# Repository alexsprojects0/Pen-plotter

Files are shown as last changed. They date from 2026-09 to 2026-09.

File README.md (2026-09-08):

# Pen-plotter
A 180mm × 106.5mm pen plotter, driven by four 28BYJ-48 stepper motors. It can run on any microcontroller with at least 12 output pins, but all my code is written for the Arduino Uno.

Items list
2 (608-2RS bearings)
1 (Pen)
4 (28BYJ-48 stepper motors)
~200g (filament)
2 (M3 bolts any size)
2 (M3 bolts 7mm or less)
2 (M3 bolts 10mm or less)
1 (Power supply ~5 volts and at least 2amps)

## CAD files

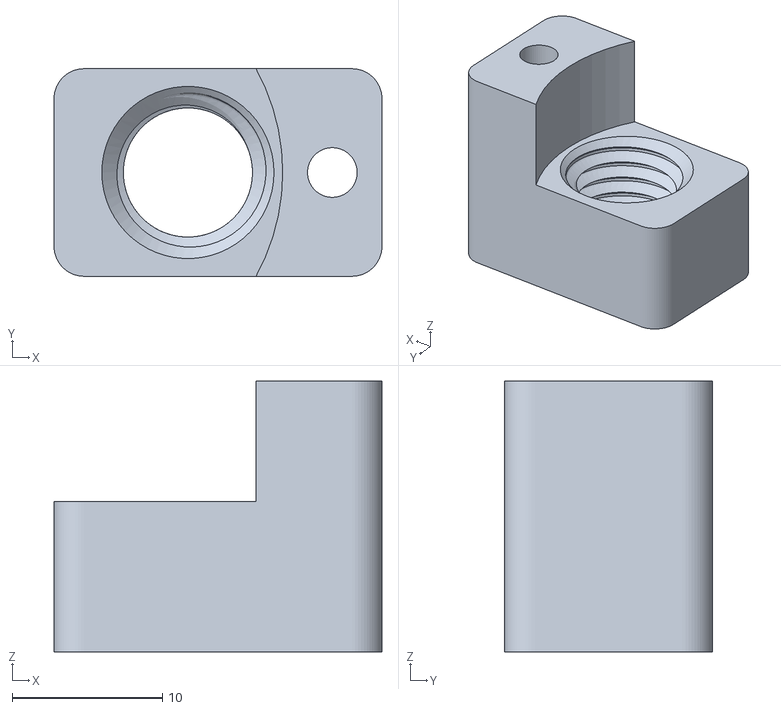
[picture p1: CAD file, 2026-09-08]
pen holder.stl
21.8 x 13.8 x 18.0

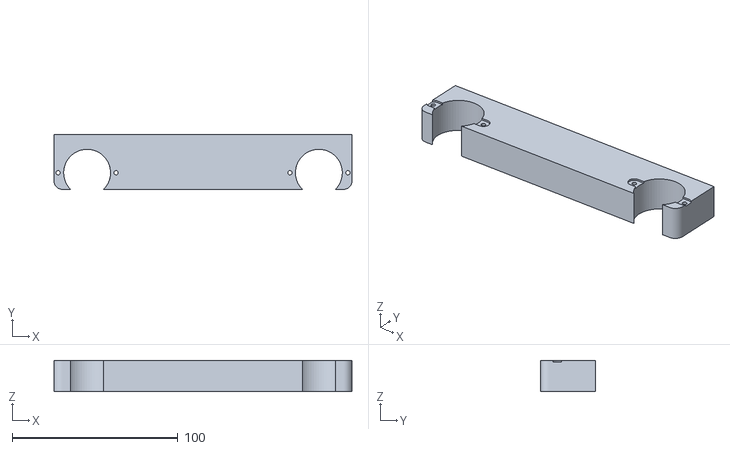
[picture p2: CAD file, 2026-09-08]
y axis base.stl
180.0 x 33.0 x 19.0

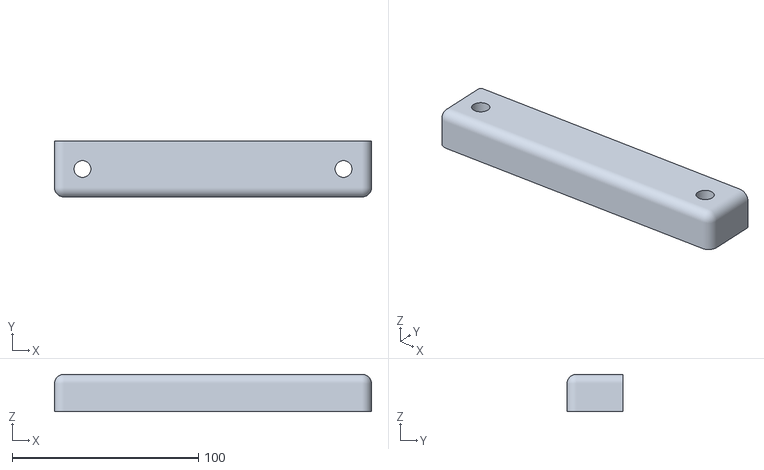
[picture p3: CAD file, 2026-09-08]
y axis support.stl
170.0 x 30.0 x 20.0

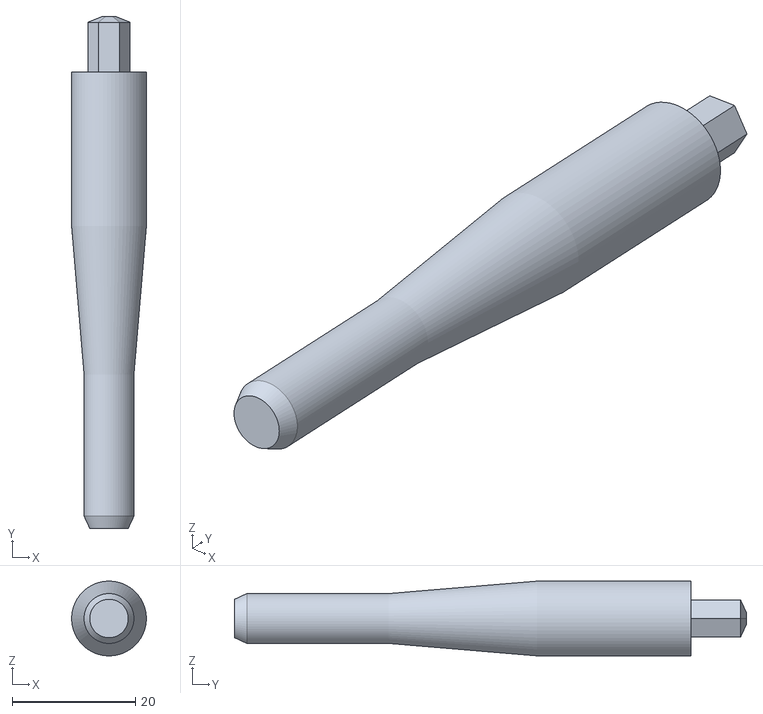
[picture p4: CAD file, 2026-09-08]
coulper.stl
12.1 x 83.0 x 12.1

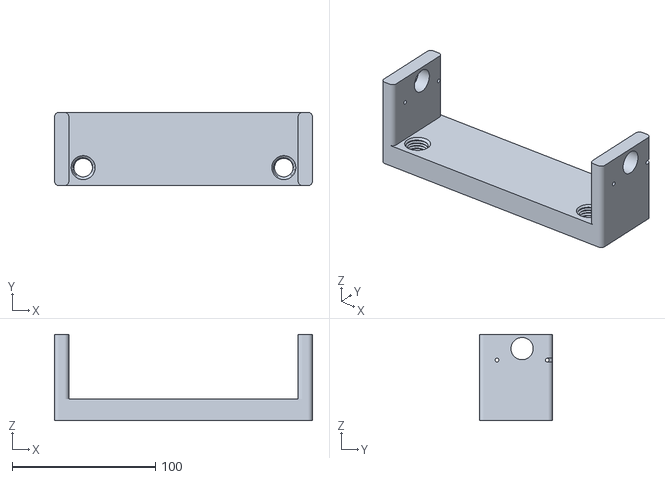
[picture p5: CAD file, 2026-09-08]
x axis base.stl
180.0 x 51.0 x 60.3

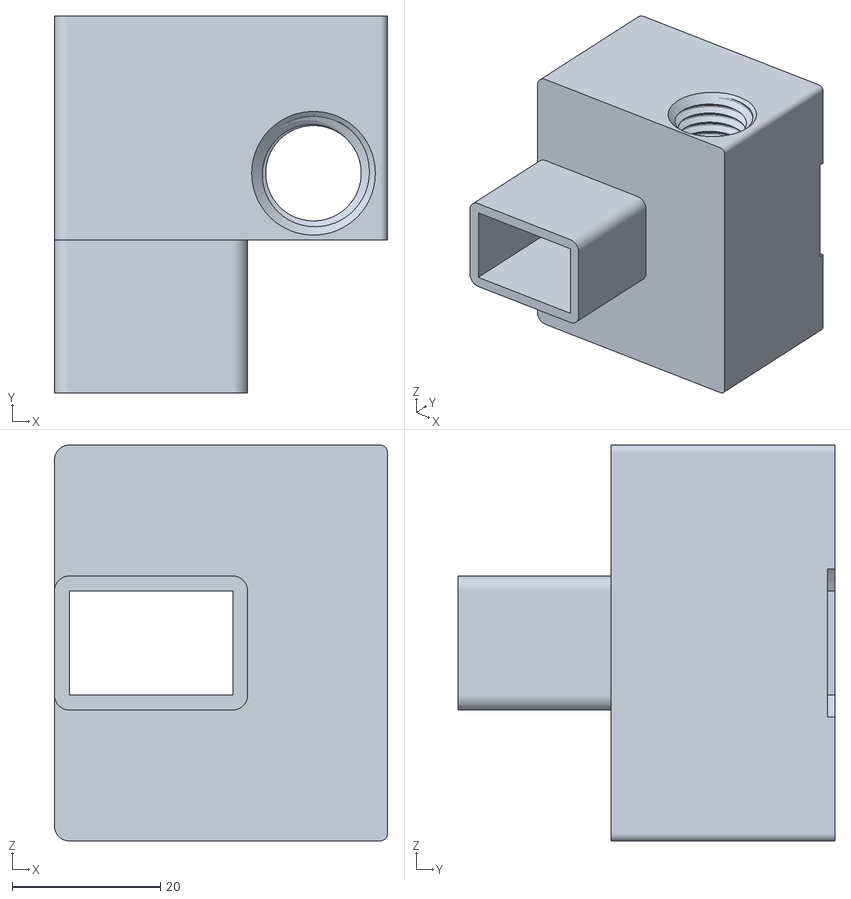
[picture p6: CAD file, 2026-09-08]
z axis base.stl
45.0 x 50.9 x 53.5

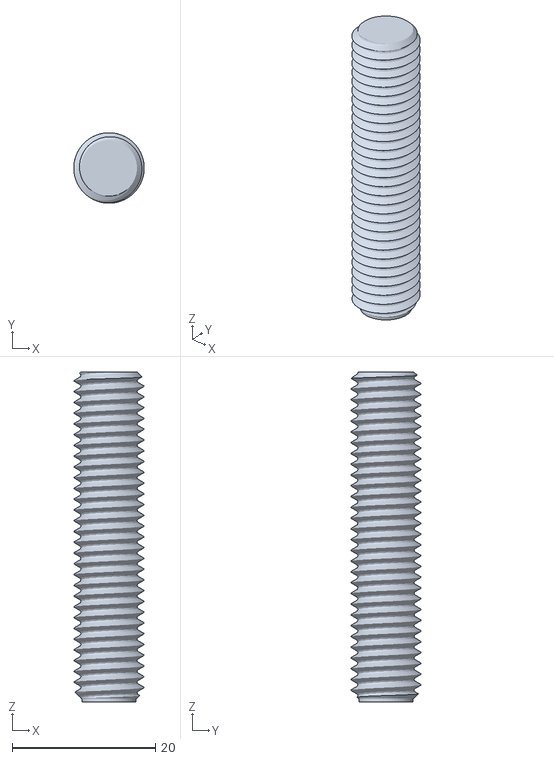
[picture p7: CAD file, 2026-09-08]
z screw.stl
9.83 x 9.83 x 46.0

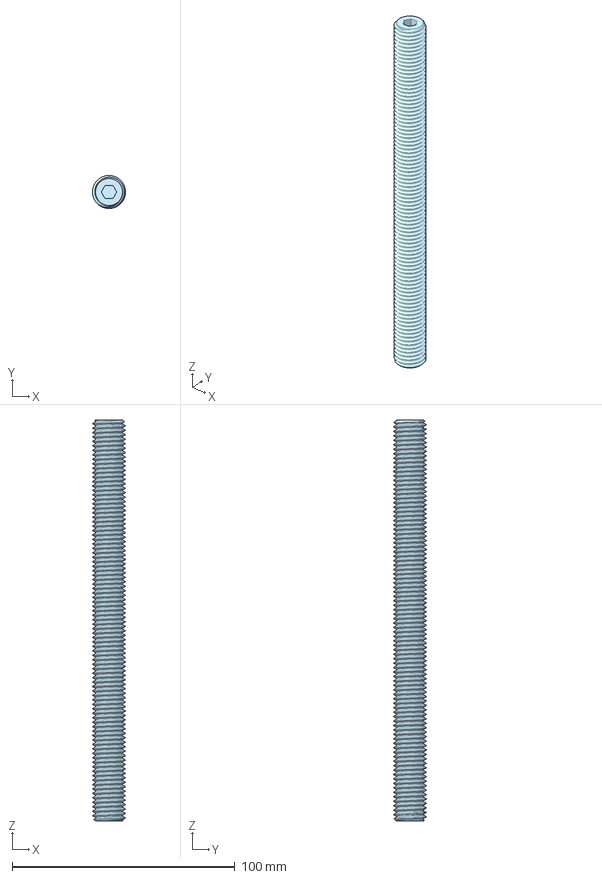
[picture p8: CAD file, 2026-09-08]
180mm screw.step
14.8 x 14.8 x 180.0 mm

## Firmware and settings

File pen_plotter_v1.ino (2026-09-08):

/*
  Pen plotter firmware - Arduino Uno, 4x 28BYJ-48 + ULN2003

  Axes: X (1 motor, 2mm pitch, 0-105mm), Y (2 motors, 2mm pitch, 0-166mm),
  Z (1 motor, 1.5mm pitch).

    Motor   IN1  IN2  IN3  IN4
    X       2    4    3    5
    Y1      6    8    7    9
    Y2      10   12   11   13
    Z       A0   A2   A1   A3

  Serial protocol (9600 baud):
    G1 X<mm> Y<mm>      move to position
    M3 / M5             pen down / pen up
    M2                  end job, return to 0,0
    JOGZ<mm>             nudge Z (+ down, - up)
    JOGX<mm> / JOGY<mm> nudge X/Y directly
    SETPOS X<mm> Y<mm>  set current position without moving
    SETDOWN / SETUP     mark current Z as down/up without moving
*/

#include <AccelStepper.h>
#include <MultiStepper.h>

#define X_IN1 2
#define X_IN2 4
#define X_IN3 3
#define X_IN4 5

#define Y1_IN1 6
#define Y1_IN2 8
#define Y1_IN3 7
#define Y1_IN4 9

#define Y2_IN1 10
#define Y2_IN2 12
#define Y2_IN3 11
#define Y2_IN4 13

#define Z_IN1 A0
#define Z_IN2 A2
#define Z_IN3 A1
#define Z_IN4 A3

const float STEPS_PER_REV = 4096.0;

const float X_PITCH_MM = 2.0;
const float Y_PITCH_MM = 2.0;
const float Z_PITCH_MM = 1.5;

const float X_STEPS_PER_MM = STEPS_PER_REV / X_PITCH_MM;
const float Y_STEPS_PER_MM = STEPS_PER_REV / Y_PITCH_MM;
const float Z_STEPS_PER_MM = STEPS_PER_REV / Z_PITCH_MM;

const float X_MAX_MM = 105.0;
const float Y_MAX_MM = 166.0;

const float Z_LIFT_MM = 3.0;
const long  Z_LIFT_STEPS = (long)(Z_LIFT_MM * Z_STEPS_PER_MM);

const float XY_MAX_SPEED = 350.0;
const float Z_MAX_SPEED  = 300.0;

AccelStepper motorX (AccelStepper::HALF4WIRE, X_IN1, X_IN3, X_IN2, X_IN4);
AccelStepper motorY1(AccelStepper::HALF4WIRE, Y1_IN1, Y1_IN3, Y1_IN2, Y1_IN4);
AccelStepper motorY2(AccelStepper::HALF4WIRE, Y2_IN1, Y2_IN3, Y2_IN2, Y2_IN4);
AccelStepper motorZ (AccelStepper::HALF4WIRE, Z_IN1, Z_IN3, Z_IN2, Z_IN4);

MultiStepper xySync;

float curX_mm = 0.0;
float curY_mm = 0.0;
bool penIsDown = true;

void setup() {
  Serial.begin(9600);

  motorX.setMaxSpeed(XY_MAX_SPEED);
  motorY1.setMaxSpeed(XY_MAX_SPEED);
  motorY2.setMaxSpeed(XY_MAX_SPEED);
  motorZ.setMaxSpeed(Z_MAX_SPEED);

  xySync.addStepper(motorX);
  xySync.addStepper(motorY1);
  xySync.addStepper(motorY2);

  Serial.println(F("Pen plotter ready. Assumes pen DOWN at X0 Y0."));
  Serial.println(F("ok"));
}

void loop() {
  if (Serial.available()) {
    String line = Serial.readStringUntil('\n');
    line.trim();
    if (line.length() > 0) {
      handleCommand(line);
      Serial.println(F("ok"));
    }
  }
}

void handleCommand(String cmd) {
  cmd.toUpperCase();

  if (cmd.startsWith("G1")) {
    float targetX = curX_mm;
    float targetY = curY_mm;

    int xIdx = cmd.indexOf('X');
    int yIdx = cmd.indexOf('Y');

    if (xIdx != -1) targetX = cmd.substring(xIdx + 1).toFloat();
    if (yIdx != -1) targetY = cmd.substring(yIdx + 1).toFloat();

    moveTo(targetX, targetY);
  }
  else if (cmd.startsWith("M3")) {
    penDown();
  }
  else if (cmd.startsWith("M5")) {
    penUp();
  }
  else if (cmd.startsWith("M2")) {
    endJob();
  }
  else if (cmd.startsWith("JOGX")) {
    float jogMm = cmd.substring(4).toFloat();
    long jogSteps = (long)(jogMm * X_STEPS_PER_MM);
    motorX.move(jogSteps);
    runToCompletion(motorX);
    disableXY();
  }
  else if (cmd.startsWith("JOGY")) {
    float jogMm = cmd.substring(4).toFloat();
    long jogSteps = (long)(jogMm * Y_STEPS_PER_MM);
    motorY1.move(jogSteps);
    motorY2.move(jogSteps);
    runToCompletionTwo(motorY1, motorY2);
    disableXY();
  }
  else if (cmd.startsWith("JOGZ")) {
    float jogMm = cmd.substring(3).toFloat();
    long jogSteps = (long)(jogMm * Z_STEPS_PER_MM);
    motorZ.move(jogSteps);
    runToCompletion(motorZ);
    disableZ();
  }
  else if (cmd.startsWith("SETPOS")) {
    int xIdx = cmd.indexOf('X');
    int yIdx = cmd.indexOf('Y');
    if (xIdx != -1) curX_mm = cmd.substring(xIdx + 1).toFloat();
    if (yIdx != -1) curY_mm = cmd.substring(yIdx + 1).toFloat();
    Serial.print(F("Position set to X"));
    Serial.print(curX_mm);
    Serial.print(F(" Y"));
    Serial.println(curY_mm);
  }
  else if (cmd.startsWith("SETDOWN")) {
    penIsDown = true;
    Serial.println(F("Marked current position as pen-down."));
  }
  else if (cmd.startsWith("SETUP")) {
    penIsDown = false;
    Serial.println(F("Marked current position as pen-up."));
  }
  else {
    Serial.print(F("Unknown command: "));
    Serial.println(cmd);
  }
}

void moveTo(float xmm, float ymm) {
  xmm = constrain(xmm, 0.0, X_MAX_MM);
  ymm = constrain(ymm, 0.0, Y_MAX_MM);

  long xSteps = (long)(xmm * X_STEPS_PER_MM);
  long ySteps = (long)(ymm * Y_STEPS_PER_MM);

  long targets[3] = { xSteps, ySteps, ySteps };
  xySync.moveTo(targets);

  while (xySync.run()) {}

  curX_mm = xmm;
  curY_mm = ymm;

  disableXY();
}

void penDown() {
  if (!penIsDown) {
    motorZ.move(Z_LIFT_STEPS);
    runToCompletion(motorZ);
    penIsDown = true;
    disableZ();
  }
}

void penUp() {
  if (penIsDown) {
    motorZ.move(-Z_LIFT_STEPS);
    runToCompletion(motorZ);
    penIsDown = false;
    disableZ();
  }
}

void endJob() {
  penUp();
  moveTo(0.0, 0.0);
  disableXY();
  disableZ();
  Serial.println(F("Job complete. Returned to origin, pen up."));
}

void runToCompletion(AccelStepper &motor) {
  motor.setSpeed(motor.maxSpeed());
  while (motor.distanceToGo() != 0) {
    motor.runSpeedToPosition();
  }
}

void runToCompletionTwo(AccelStepper &m1, AccelStepper &m2) {
  m1.setSpeed(m1.maxSpeed());
  m2.setSpeed(m2.maxSpeed());
  while (m1.distanceToGo() != 0 || m2.distanceToGo() != 0) {
    if (m1.distanceToGo() != 0) m1.runSpeedToPosition();
    if (m2.distanceToGo() != 0) m2.runSpeedToPosition();
  }
}

void disableXY() {
  motorX.disableOutputs();
  motorY1.disableOutputs();
  motorY2.disableOutputs();
}

void disableZ() {
  motorZ.disableOutputs();
}

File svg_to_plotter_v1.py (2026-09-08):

#!/usr/bin/env python3
"""
Converts SVG line art into the plotter's serial protocol (G1/M3/M5/M2)
and streams it to the Arduino over USB.

Usage:
    python svg_to_plotter.py drawing.svg --port COM5
    python svg_to_plotter.py drawing.svg --dry-run
"""

import argparse
import math
import re
import sys
import time
import xml.etree.ElementTree as ET

BED_X_MM = 105.0
BED_Y_MM = 166.0
MARGIN_MM = 5.0

CURVE_SEGMENTS = 20

TOKEN_RE = re.compile(r"[MmLlHhVvCcSsQqTtAaZz]|-?\d*\.?\d+(?:[eE][-+]?\d+)?")


def parse_path_d(d):
    tokens = TOKEN_RE.findall(d)
    i = 0

    def next_num():
        nonlocal i
        val = float(tokens[i])
        i += 1
        return val

    subpaths = []
    current = []
    cur = (0.0, 0.0)
    start = (0.0, 0.0)
    last_ctrl = None
    cmd = None

    while i < len(tokens):
        tok = tokens[i]
        if re.match(r"[A-Za-z]", tok):
            cmd = tok
            i += 1

        if cmd in ("M", "m"):
            x, y = next_num(), next_num()
            if cmd == "m" and current:
                x += cur[0]; y += cur[1]
            if current:
                subpaths.append(current)
            current = [(x, y)]
            cur = (x, y)
            start = cur
            last_ctrl = None
            cmd = "L" if cmd == "M" else "l"

        elif cmd in ("L", "l"):
            x, y = next_num(), next_num()
            if cmd == "l":
                x += cur[0]; y += cur[1]
            current.append((x, y))
            cur = (x, y)
            last_ctrl = None

        elif cmd in ("H", "h"):
            x = next_num()
            if cmd == "h":
                x += cur[0]
            current.append((x, cur[1]))
            cur = (x, cur[1])
            last_ctrl = None

        elif cmd in ("V", "v"):
            y = next_num()
            if cmd == "v":
                y += cur[1]
            current.append((cur[0], y))
            cur = (cur[0], y)
            last_ctrl = None

        elif cmd in ("C", "c"):
            x1, y1, x2, y2, x, y = (next_num() for _ in range(6))
            if cmd == "c":
                x1 += cur[0]; y1 += cur[1]
                x2 += cur[0]; y2 += cur[1]
                x += cur[0]; y += cur[1]
            current.extend(_cubic_bezier(cur, (x1, y1), (x2, y2), (x, y)))
            cur = (x, y)
            last_ctrl = (x2, y2)

        elif cmd in ("S", "s"):
            x2, y2, x, y = (next_num() for _ in range(4))
            if cmd == "s":
                x2 += cur[0]; y2 += cur[1]
                x += cur[0]; y += cur[1]
            if last_ctrl:
                x1 = 2 * cur[0] - last_ctrl[0]
                y1 = 2 * cur[1] - last_ctrl[1]
            else:
                x1, y1 = cur
            current.extend(_cubic_bezier(cur, (x1, y1), (x2, y2), (x, y)))
            cur = (x, y)
            last_ctrl = (x2, y2)

        elif cmd in ("Q", "q"):
            x1, y1, x, y = (next_num() for _ in range(4))
            if cmd == "q":
                x1 += cur[0]; y1 += cur[1]
                x += cur[0]; y += cur[1]
            current.extend(_quad_bezier(cur, (x1, y1), (x, y)))
            cur = (x, y)
            last_ctrl = (x1, y1)

        elif cmd in ("T", "t"):
            x, y = next_num(), next_num()
            if cmd == "t":
                x += cur[0]; y += cur[1]
            if last_ctrl:
                x1 = 2 * cur[0] - last_ctrl[0]
                y1 = 2 * cur[1] - last_ctrl[1]
            else:
                x1, y1 = cur
            current.extend(_quad_bezier(cur, (x1, y1), (x, y)))
            cur = (x, y)
            last_ctrl = (x1, y1)

        elif cmd in ("A", "a"):
            rx, ry, rot, large, sweep, x, y = (next_num() for _ in range(7))
            if cmd == "a":
                x += cur[0]; y += cur[1]
            current.append((x, y))
            cur = (x, y)
            last_ctrl = None

        elif cmd in ("Z", "z"):
            current.append(start)
            cur = start
            subpaths.append(current)
            current = []
            last_ctrl = None

        else:
            i += 1

    if current:
        subpaths.append(current)
    return subpaths


def _cubic_bezier(p0, p1, p2, p3, n=CURVE_SEGMENTS):
    pts = []
    for k in range(1, n + 1):
        t = k / n
        mt = 1 - t
        x = (mt**3 * p0[0] + 3 * mt**2 * t * p1[0] +
             3 * mt * t**2 * p2[0] + t**3 * p3[0])
        y = (mt**3 * p0[1] + 3 * mt**2 * t * p1[1] +
             3 * mt * t**2 * p2[1] + t**3 * p3[1])
        pts.append((x, y))
    return pts


def _quad_bezier(p0, p1, p2, n=CURVE_SEGMENTS):
    pts = []
    for k in range(1, n + 1):
        t = k / n
        mt = 1 - t
        x = mt**2 * p0[0] + 2 * mt * t * p1[0] + t**2 * p2[0]
        y = mt**2 * p0[1] + 2 * mt * t * p1[1] + t**2 * p2[1]
        pts.append((x, y))
    return pts


def _strip_ns(tag):
    return tag.split("}")[-1] if "}" in tag else tag


IDENTITY = (1.0, 0.0, 0.0, 1.0, 0.0, 0.0)


def _compose(m1, m2):
    a1, b1, c1, d1, e1, f1 = m1
    a2, b2, c2, d2, e2, f2 = m2
    return (
        a1 * a2 + c1 * b2,
        b1 * a2 + d1 * b2,
        a1 * c2 + c1 * d2,
        b1 * c2 + d1 * d2,
        a1 * e2 + c1 * f2 + e1,
        b1 * e2 + d1 * f2 + f1,
    )


def _apply(m, x, y):
    a, b, c, d, e, f = m
    return (a * x + c * y + e, b * x + d * y + f)


def parse_transform(s):
    combined = IDENTITY
    for name, args in re.findall(r"(\w+)\s*\(([^)]*)\)", s or ""):
        nums = [float(v) for v in
                re.findall(r"-?\d*\.?\d+(?:[eE][-+]?\d+)?", args)]
        if name == "matrix" and len(nums) == 6:
            m = tuple(nums)
        elif name == "translate":
            tx = nums[0] if nums else 0.0
            ty = nums[1] if len(nums) > 1 else 0.0
            m = (1.0, 0.0, 0.0, 1.0, tx, ty)
        elif name == "scale":
            sx = nums[0] if nums else 1.0
            sy = nums[1] if len(nums) > 1 else sx
            m = (sx, 0.0, 0.0, sy, 0.0, 0.0)
        elif name == "rotate" and nums:
            ang = math.radians(nums[0])
            cos_a, sin_a = math.cos(ang), math.sin(ang)
            rot = (cos_a, sin_a, -sin_a, cos_a, 0.0, 0.0)
            if len(nums) >= 3:
                cx, cy = nums[1], nums[2]
                m = _compose(_compose((1, 0, 0, 1, cx, cy), rot),
                             (1, 0, 0, 1, -cx, -cy))
            else:
                m = rot
        else:
            continue
        combined = _compose(combined, m)
    return combined


def load_svg_as_polylines(svg_path):
    tree = ET.parse(svg_path)
    root = tree.getroot()
    polylines = []
    _walk(root, IDENTITY, polylines)
    return polylines
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

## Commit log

2026-09-08 Pen plotter stl files
    Print two coulper.stl
    Print three 180mm screw.step
    [180mm screw.step, coulper.stl, pen holder.stl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]
2026-09-08 Code
    open pen_plotter_v1.ino in the arduino ide
    Run svg_to_plotter_v1.py and simulate_plotter_v1.py in python
